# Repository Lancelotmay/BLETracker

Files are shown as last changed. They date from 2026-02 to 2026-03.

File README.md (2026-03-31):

# BLETracker

Copyright (C) 2026 Lancelot MEI

BLETracker is a Zephyr-based firmware project for a Bluetooth Low Energy tracker built around a Nordic nRF52840 platform and a u-blox SAM-M10 GNSS module. The repository also contains the associated board definition files and schematic design files.

## Overview

BLETracker is a portable external GNSS positioning device designed to work with a smartphone over BLE. It augments the phone’s built-in GNSS by offloading positioning to a dedicated low-power device.

Compared to relying solely on the phone, BLETracker focuses on delivering longer tracking duration and more stable positioning, while the phone remains the main interface for display, storage, and connectivity.

The system focuses on three practical goals:

- **Longer tracking time**: GNSS is handled by a dedicated device, reducing continuous GNSS load on the phone.
- **More stable positioning**: a standalone GNSS module with better antenna conditions can provide more consistent fixes during movement.
- **Simple integration**: location data is transmitted via BLE and can be consumed by a mobile app or logging system.

## Why this project

- Continuous GNSS on a phone drains battery quickly.
- Antenna constraints and device placement affect stability.
- Limited control over GNSS behavior for logging use cases.

BLETracker acts as an external GNSS sensor over BLE, offloading positioning while the phone handles UI and data.

## Design considerations

- **Low-power system design**: nRF52840 manages BLE communication and system control with efficient scheduling.
- **Dedicated GNSS module**: u-blox SAM-M10 is used for its power efficiency and reliable positioning performance.
- **Separation of concerns**: GNSS acquisition, BLE transport, and application logic are decoupled.
- **Portable form factor**: intended to be carried or attached during activity.

## Potential use cases

- Long-duration walking, hiking, or cycling with continuous track logging
- External GNSS receiver for mobile applications
- Lightweight positioning device for custom data collection
- Development platform for GNSS-related experiments

## Hardware

- Schematics and PCB design files are located under `hardware/` (KiCad sources).

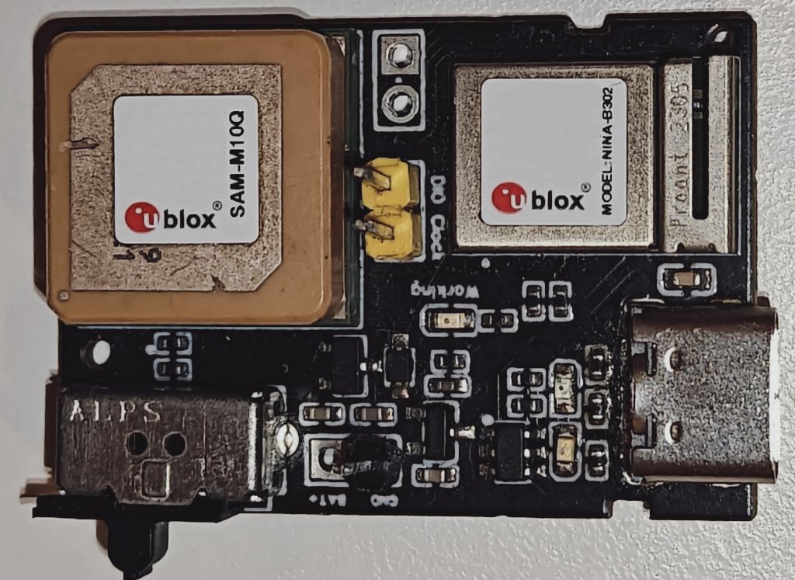
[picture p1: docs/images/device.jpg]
BLETracker device

## Repository layout

- `src/`: application firmware, BLE services, GNSS/UBX handling, and hardware glue.
- `boards/IMYTH/BLETracker/`: custom Zephyr board definition for the target hardware.
- `docs/`: project notes and design documents.
- `hardware/`: KiCad source files (converted from EasyCAD, need adjust) and related hardware assets.

## Build notes

This project is intended to be built with Zephyr and a configured Zephyr SDK / toolchain environment.

Typical build flow:

```sh
west build -b BLETracker/nrf52840
```

You may need to adjust the board target or workspace layout to match your local Zephyr setup.

## GitHub readiness notes

- `build/` and local editor state are intentionally ignored.
- `.vscode/` contains machine-local IDE configuration and is not required to build the project.
- `src/ubx_messages_header.h` is a generated u-blox header and retains its original upstream notice.

## License

Unless a file states otherwise, this repository is licensed under `GPL-2.0-only`. See [LICENSE](LICENSE).

Third-party or generated files may carry their own notices and should be treated according to the license text embedded in those files.

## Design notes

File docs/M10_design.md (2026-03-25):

<!--
Copyright (C) 2026 Lancelot MEI
SPDX-License-Identifier: GPL-2.0-only
-->

## app_M10 design

single thread
app -> ubx -> M10_hw

Buffer management (ring buffers)
static allocation, __aligned(32)
rx buffer: rx_buff_num x max rx message size
tx buffer: tx_buff_num x max tx message size

work items:
- when ISR trigger, decode rx message and update LNS
- when new config received, update M10 configuration
- GNSS state management (TBD)
- GNSS init sequence

system init:
    - interface init
    - BATT init
    - GNSS init
      - reset GNSS
      - disable all message
      - read version info
      - put GNSS in sleep
    - BLE init

triggers
- batt timer: put BATT reading to Workqueue: read ADC, send via BLE
- Start GNSS:
  - bluetooth get config from M10 setting profile (priviate) and notify main thread
  - main thread allocate buffer and send config to M10
  - enable 1pps interrupt
- 1pps interrrupt 
  - send signal to main thread
    - main  thread allocate buffer for PVT message
    - main thread poll PVT message;
    - main thread build and send PVT result to BLE
    - release buffer

UBX operations
- poll message:
  - build message payload
  - build message
  - send message
  - wait 10ms
  - check for response
  - decode response
- send message
-

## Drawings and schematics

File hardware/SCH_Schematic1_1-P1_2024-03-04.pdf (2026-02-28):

# LDO

## USB/battery switch

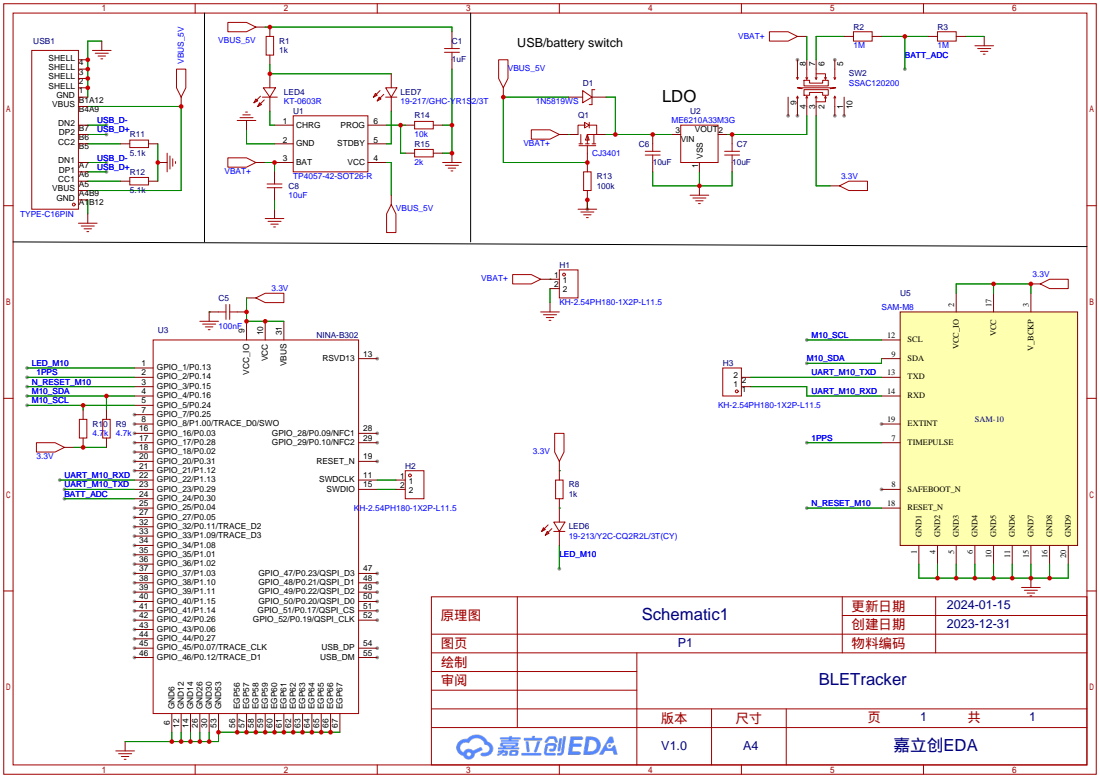
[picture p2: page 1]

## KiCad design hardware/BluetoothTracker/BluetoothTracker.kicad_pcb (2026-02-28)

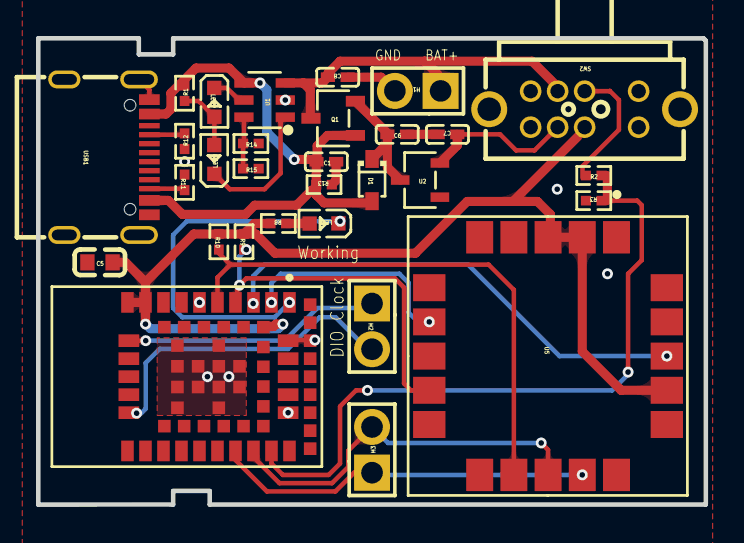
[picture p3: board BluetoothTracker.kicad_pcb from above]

Board: 2 copper layers, 37.1 x 25.9 mm, 30 parts (0 on the bottom side), 26 nets.

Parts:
C1, C6, C7, C8: C0402
C5: C0603
D1: SOD-323_L1.8-W1.3-LS2.5-RD
H1, H2, H3: HDR-TH_2P-P2.54-V-M
LED4, LED7: LED0603-RD
LED6: LED0603-RD-YELLOW
Q1: SOT-23-3_L2.9-W1.6-P1.90-LS2.8-BR
R1, R2, R3, R8, R9, R10, R11, R12, R13, R14, R15: R0402
SW2: SW-TH_SSAC120200
U1: SOT-23-6_L2.9-W1.6-P0.95-LS2.8-BL
U2: SOT-23-3_L3.0-W1.7-P0.95-LS2.9-BR
U3: NINA_LGA67R_1500X1000X338_PIFA
U5: SAM-M8
USB1: USB-C-SMD_TYPE-C16PIN

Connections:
1PPS: U3.2, U5.7
3.3V: C5.2, R8.2, R9.1, R10.1, SW2.2, U3.9, U3.10, U3.31, U5.2, U5.3, U5.17
$1N2952: R11.2, USB1.B5
$1N2955: R12.2, USB1.A5
$1N6137: LED4.1, U1.1
$1N6365: LED4.2, LED7.2, R1.1
$1N6477: LED7.1, U1.5
$1N8277: C6.1, D1.1, Q1.2, U2.3
$1N11360: H2.1, U3.11
$1N11362: H2.2, U3.15
$1N22575: R2.1, SW2.6
$1N22590: C7.1, SW2.3, U2.2
$1N23834: LED6.2, R8.1
$1N24373: R14.1, R15.1, U1.6
BATT_ADC: R2.2, R3.1, U3.24
GND: C1.2, C5.1, C6.2, C7.2, C8.1, H1.2, R3.2, R11.1, R12.1, R13.1, R14.2, R15.2, U1.2, U2.1, U3.6, U3.12, U3.14, U3.26, U3.30, U3.53, U3.56, U3.57, U3.58, U3.59, U3.60, U3.61, U3.62, U3.63, U3.64, U3.65, U3.66, U3.67, U5.1, U5.4, U5.5, U5.6, U5.10, U5.11, U5.15, U5.16, U5.20, USB1.1, USB1.2, USB1.3, USB1.4, USB1.A1B12, USB1.B1A12
LED_M10: LED6.1, U3.1
M10_SCL: R10.2, U3.5, U5.12
M10_SDA: R9.2, U3.4, U5.9
N_RESET_M10: U3.3, U5.18
UART_M10_RXD: H3.1, U3.22, U5.14
UART_M10_TXD: H3.2, U3.23, U5.13
USB_D+: USB1.A6, USB1.B6
USB_D-: USB1.A7, USB1.B7
VBAT+: C8.2, H1.1, Q1.3, SW2.7, U1.3
VBUS_5V: C1.1, D1.2, Q1.1, R1.2, R13.2, U1.4, USB1.A4B9, USB1.B4A9

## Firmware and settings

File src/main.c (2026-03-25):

/*
 * Copyright (C) 2026 Lancelot MEI
 * SPDX-License-Identifier: GPL-2.0-only
 */

#include <zephyr/kernel.h>
#include <zephyr/logging/log.h>
#include <zephyr/sys/util.h>

#include "M10_hw.h"
#include "app_battery.h"
#include "app_m10.h"
#include "ble_core.h"


LOG_MODULE_REGISTER(main, LOG_LEVEL_INF);

enum {
	EVT_1PPS_TICK = BIT(0),
	EVT_BLE_CONFIG_UPDATED = BIT(1),
	EVT_PVT_TIMER = BIT(2),
};


static struct k_event main_events;

static void m10_pps_cb(void *user_data)
{
	struct k_event *ev = user_data;

	if (ev != NULL) {
		k_event_post(ev, EVT_1PPS_TICK);
	}
}

static void pvt_timer_hander(struct k_timer *timer)
{
	k_event_post(&main_events, EVT_PVT_TIMER);
}
static K_TIMER_DEFINE(pvt_timer, pvt_timer_hander, NULL);

int main(void)
{
    int err;
	uint32_t events;

    LOG_INF("BLE Tracker starting via RTT...\n");
    /* Hardware Init */

    err = ble_init();
    if (err) {
        LOG_ERR("BLE init failed, err %d\n", err);
        return err;
    }
    /* Init battery monitoring */
    err = app_battery_init();
    if (err){
        LOG_ERR("BATT Mon ERR %d\n", err);
    } else {
        app_battery_start();
    }

    err = app_m10_init();
    if (err != 0) {
        LOG_ERR("M10 init failed (err %d)", err);
		return err;
    }

	err = app_m10_start();
	if (err != 0) {
		LOG_ERR("M10 start failed (err %d)", err);
		return err;
	}

	k_event_init(&main_events);

	err = M10_hw_pps_enable(m10_pps_cb, &main_events);
	if (err != 0) {
		LOG_ERR("M10 1PPS enable failed (err %d)", err);
		return err;
	}
	k_timer_start(&pvt_timer, K_SECONDS(3), K_SECONDS(1));
	while (1) {
		events = k_event_wait(&main_events,
            EVT_1PPS_TICK | EVT_BLE_CONFIG_UPDATED|EVT_PVT_TIMER,
                    true, K_FOREVER);
		if ((events & EVT_1PPS_TICK) != 0U) {
			M10_led_set(1);
			k_timer_start(&pvt_timer, K_MSEC(200U), K_NO_WAIT);
		}
		if ((events & EVT_PVT_TIMER) != 0U) {
			if (ble_lns_notify_is_enabled()) {
				err = m10_pvt_update();
				if (err != 0) {
					LOG_DBG("PVT update skipped/failed (err %d)", err);
				}	
			}
			M10_led_toggle();
		}

		if ((events & EVT_BLE_CONFIG_UPDATED) != 0U) {
			LOG_DBG("BLE config update event received (TODO)");
		}
	}
}

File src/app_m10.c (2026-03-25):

/*
 * Copyright (C) 2026 Lancelot MEI
 * SPDX-License-Identifier: GPL-2.0-only
 */

#include "app_m10.h"
#include <errno.h>
#include <limits.h>
#include <string.h>
#include "ubx_messages_header.h"
#include "ubx_messages_header_custom.h"

#include <zephyr/bluetooth/conn.h>
#include <zephyr/kernel.h>
#include <zephyr/logging/log.h>
#include <zephyr/sys/util.h>

#include "M10_hw.h"
#include "ble_core.h"
#include "ble_lns.h"
#include "ubx.h"

LOG_MODULE_REGISTER(app_m10, LOG_LEVEL_INF);

#define APP_M10_RX_BUFFER_SIZE 4
#define APP_M10_TX_BUFFER_SIZE 4
#define UBX_CFG_LAYER_RAM 0x01u

/* M10 configuration database keys for message output rate on I2C (U1). */
#define CFG_MSGOUT_UBX_NAV_PVT_I2C_U1 0X20910006UL
#define CFG_MSGOUT_NMEA_ID_DTM_I2C_U1 0X209100A6UL
#define CFG_MSGOUT_NMEA_ID_GGA_I2C_U1 0X209100BAUL
#define CFG_MSGOUT_NMEA_ID_GLL_I2C_U1 0X209100C9UL
#define CFG_MSGOUT_NMEA_ID_GNS_I2C_U1 0X209100B5UL
#define CFG_MSGOUT_NMEA_ID_GRS_I2C_U1 0X209100CEUL
#define CFG_MSGOUT_NMEA_ID_GSA_I2C_U1 0X209100BFUL
#define CFG_MSGOUT_NMEA_ID_GST_I2C_U1 0X209100D3UL
#define CFG_MSGOUT_NMEA_ID_GSV_I2C_U1 0X209100C4UL
#define CFG_MSGOUT_NMEA_ID_RMC_I2C_U1 0X209100ABUL
#define CFG_MSGOUT_NMEA_ID_VLW_I2C_U1 0X209100E7UL
#define CFG_MSGOUT_NMEA_ID_VTG_I2C_U1 0X209100B0UL
#define CFG_MSGOUT_NMEA_ID_ZDA_I2C_U1 0X209100D8UL

/* buffer for tx and rx*/
static uint8_t rx_buffer[UBX_MAX_RX_MSG_LENGTH];
static uint8_t tx_buffer[UBX_MAX_TX_MSG_LENGTH];
static bool started;

static int app_m10_configure_valset(void);

static inline int32_t mod(int32_t a, int32_t b) {
    int32_t r = a % b;
    return r < 0 ? r + b : r;
}

int m10_pvt_update(void)
{
    int err;
    uint16_t rx_len = 0;
    uint16_t rx_msg_len = 0;
    struct ble_lns_loc_speed fix;
    struct bt_conn* conn;
    UBX_NAV_PVT_DATA1_t* pvt;
    bool fix_ok;
    bool time_ok;
    int32_t gspeed_mm_s;
    uint16_t expected_len = UBX_HEAD_SIZE + sizeof(UBX_NAV_PVT_DATA1_t) + UBX_CHKSUM_SIZE;

    err = ubx_poll_message(UBXID_NAV_PVT, tx_buffer, rx_buffer, &rx_len, 80U);
    if (err != 0) {
        LOG_ERR("PVT query failed (err %d)", err);
        return err;
    }
    if (rx_len < expected_len) {
        LOG_ERR("PVT msg too short (%u bytes)", rx_len);
        return -EMSGSIZE;
    } else {
        err = ubx_verify_msg(rx_buffer, rx_len, &rx_msg_len);
        if (err != 0) {
            LOG_ERR("PVT decode failed (err %d)", err);
            return err;
        }
    }

    pvt = (UBX_NAV_PVT_DATA1_t*)&(rx_buffer[UBX_HEAD_SIZE]);

    fix_ok = (UBX_NAV_PVT_DATA1_FLAGS_GNSSFIXOK_GET(pvt->flags) != 0U);
    time_ok = (UBX_NAV_PVT_DATA1_VALID_VALIDDATE_GET(pvt->valid) != 0U) &&
                (UBX_NAV_PVT_DATA1_VALID_VALIDTIME_GET(pvt->valid) != 0U);

    memset(&fix, 0, sizeof(fix));
    fix.flags = 0U;

    if (fix_ok) {
        fix.flags = (BLE_LNS_LOC_SPEED_INST_SPEED_PRESENT | BLE_LNS_LOC_SPEED_LOCATION_PRESENT |
                        BLE_LNS_LOC_SPEED_HEADING_PRESENT |
                        BLE_LNS_LOC_SPEED_POS_STATUS_ENCODE(BLE_LNS_POS_POSITION_OK));

		/* covert from int32 to uint16, ignore negitive speed*/
		gspeed_mm_s = pvt->gSpeed;
		if (gspeed_mm_s < 0) {
			gspeed_mm_s = 0;
		}
		fix.inst_speed = (uint16_t)MIN((uint32_t)(gspeed_mm_s / 10), (uint32_t)UINT16_MAX);

		fix.latitude = pvt->lat;
		fix.longitude = pvt->lon;
		fix.heading = (uint16_t) (mod((int32_t)(pvt->headMot / 1000), 36000));

		if (time_ok) {
			fix.flags |= BLE_LNS_LOC_SPEED_UTC_TIME_PRESENT;
			fix.utc_time.year = pvt->year;
			fix.utc_time.month = pvt->month;
			fix.utc_time.day = pvt->day;
			fix.utc_time.hours = pvt->hour;
			fix.utc_time.minutes = pvt->min;
			fix.utc_time.seconds = pvt->sec;
		}

		conn = ble_get_default_conn();
		if (conn == NULL) {
			LOG_DBG("No BLE connection; skipping LNS notify");
			return -ENOTCONN;
		}

		err = ble_lns_notify_location_speed(conn, &fix);
		if (err != 0) {
			LOG_WRN("LNS notify failed (err %d)", err);
		}
		return 0;
	} else {
		LOG_INF("No fix");
		return -ENODATA;
	}
}

static int app_m10_version_query(void)
{
    int err = -1;
    uint16_t rx_len = 0;
    uint16_t rx_msg_len = 0;
    UBX_MON_VER_t* ver = NULL;

    err = ubx_poll_message(UBXID_MON_VER, tx_buffer, rx_buffer, &rx_len, 10U);
    if ((err != 0U) || (rx_len == 0U)) {
        LOG_ERR("VER query failed (err %d)", err);
        return err;
    }
    err = ubx_verify_msg(rx_buffer, rx_len, &rx_msg_len);
    if (err != 0) {
        LOG_ERR("VER decode failed (err %d)", err);
        return err;
    }
    if (rx_len < (UBX_HEAD_SIZE + UBX_MON_VER_SIZE + UBX_CHKSUM_SIZE)) {
        LOG_ERR("VER msg too short (%u bytes)", rx_len);
        LOG_ERR("Version: %.*s", rx_len - UBX_HEAD_SIZE - UBX_CHKSUM_SIZE,
                (char*)&rx_buffer[UBX_HEAD_SIZE]);
        return -EMSGSIZE;
    }
    ver = (UBX_MON_VER_t*)&(rx_buffer[UBX_HEAD_SIZE]);
    LOG_INF("Version \n SW: %.*s, HW: %.*s", sizeof(ver->sw), ver->sw, sizeof(ver->hw), ver->hw);
    return 0;
}

static int app_m10_configure_valset(void)
{
	static const struct ubx_cfg_pair_u1 msg_cfg[] = {
		{ CFG_MSGOUT_UBX_NAV_PVT_I2C_U1, 0U },
		{ CFG_MSGOUT_NMEA_ID_DTM_I2C_U1, 0U },
		{ CFG_MSGOUT_NMEA_ID_GGA_I2C_U1, 0U },
		{ CFG_MSGOUT_NMEA_ID_GLL_I2C_U1, 0U },
		{ CFG_MSGOUT_NMEA_ID_GNS_I2C_U1, 0U },
		{ CFG_MSGOUT_NMEA_ID_GRS_I2C_U1, 0U },
		{ CFG_MSGOUT_NMEA_ID_GST_I2C_U1, 0U },
		{ CFG_MSGOUT_NMEA_ID_GSA_I2C_U1, 0U },
		{ CFG_MSGOUT_NMEA_ID_GSV_I2C_U1, 0U },
		{ CFG_MSGOUT_NMEA_ID_RMC_I2C_U1, 0U },
		{ CFG_MSGOUT_NMEA_ID_VLW_I2C_U1, 0U },
		{ CFG_MSGOUT_NMEA_ID_VTG_I2C_U1, 0U },
		{ CFG_MSGOUT_NMEA_ID_ZDA_I2C_U1, 0U },
	};
	uint16_t rx_len = 0;
	int err;

	err = ubx_cfg_valset_u1(msg_cfg, ARRAY_SIZE(msg_cfg), UBX_CFG_LAYER_RAM,
				tx_buffer, rx_buffer, &rx_len);
	if (err != 0) {
		LOG_ERR("CFG-VALSET disable default I2C outputs failed (err %d)", err);
		return err;
	}

	LOG_INF("Disabled default I2C UBX/NMEA outputs; polling only");
	return 0;
}

int app_m10_init(void)
{
    int err;

    err = M10_hw_init();
    if (err != 0) {
        return err;
    }

    LOG_INF("M10 app initialized (I2C + UBX only)");
    return 0;
}

int app_m10_start(void)
{
    int err;

    if (started) {
        return 0;
    }

    err = M10_hw_reset_pulse(5U);
    if (err != 0) {
        LOG_WRN("M10 reset pulse failed (err %d)", err);
    }
    k_sleep(K_MSEC(1000U));

    err = app_m10_version_query();
    if (err != 0) {
        LOG_ERR("M10 version query failed (err %d)", err);
        return err;
    }
    k_sleep(K_MSEC(100U));

    err = app_m10_configure_valset();
    if (err != 0) {
        LOG_WRN("M10 UBX config failed (err %d)", err);
    }

    started = true;
    LOG_INF("M10 started");
    return 0;
}
